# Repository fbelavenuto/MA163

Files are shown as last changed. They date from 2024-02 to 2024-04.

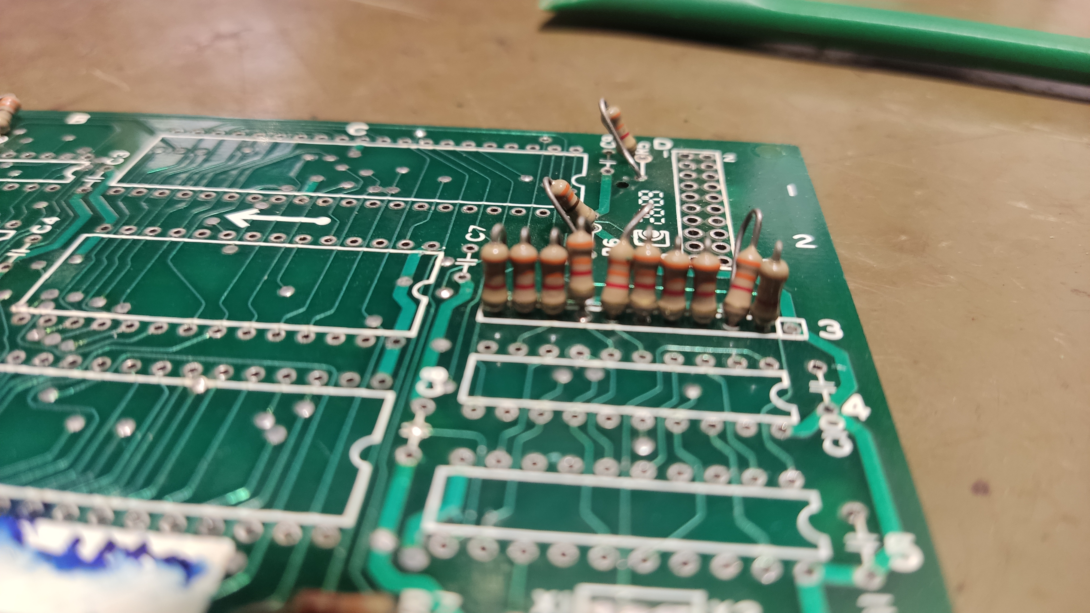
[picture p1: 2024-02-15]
Rev1/Docs/Foto02.jpg

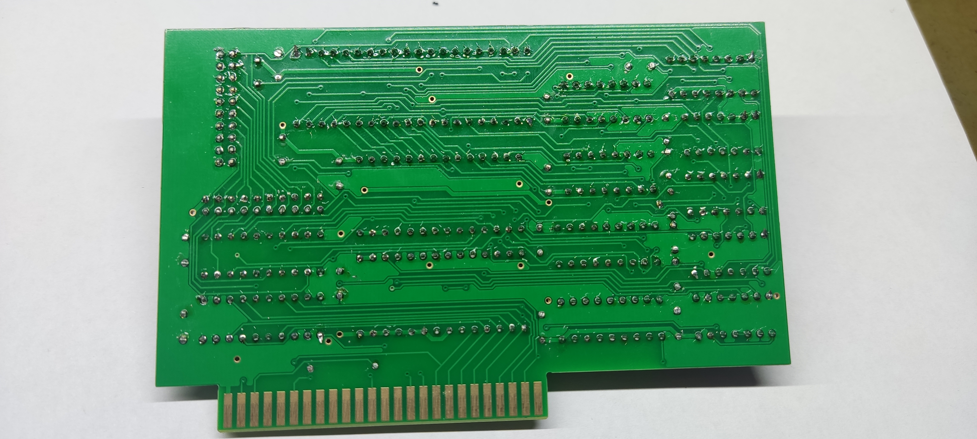
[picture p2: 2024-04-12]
Rev1/Docs/Montada-verso.jpg

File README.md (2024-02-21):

# MA163

Interface Paralela Microdigital para TK3000//e

Foi realizado uma engenharia reversa na interface paralela da Microdigital (MA163) para TK3000//e. O esquema da interface foi recriado junto com o roteamento da placa original, podendo assim ser produzido placas que funcionam como a original.

O manual original da interface digitalizado foi encontrado neste [link](http://www.apple-iigs.info/doc/fichiers/TK3000%20IIe%20Super%20parallel%20card.pdf), uma cópia do arquivo está neste repositório.

# Pastas

`Common` possui os binários das ROMs, seus *disassemblys* e uma cópia do manual original digitalizado.

Dentro da pasta [`Rev1`](Rev1) há três subpastas com os nomes `Docs`, `Eagle` e `Gerber`. O esquema elétrico em PDF, imagens, lista de materiais, etc, estão em `Docs`. Na subpasta *Eagle* há os arquivos originais para a versão 9 do software Autodesk Eagle. Para a confecção das placas há os arquivos em formato gerber na pasta `Gerber` que podem ser enviados para uma empresa de fabricação de PCBs.

# Montagem

A lista de material pode ser encontrada [aqui](Rev1/Docs/Lista%20material.md).

Para facilitar a montagem abra o arquivo [ibom.html](Rev1/Docs/ibom.html) localmente ou acesse [este link](https://fbelavenuto.github.io/pages/MA163-Rev1-ibom.html) para visualizar os componentes e seus lugares na placa. Criado com o projeto [InteractiveHtmlBom](https://github.com/openscopeproject/InteractiveHtmlBom), linha de comando: `generate_interactive_bom --highlight-pin1 all --blacklist-empty-val MA163.brd`

Soquetes para os CIs não estão na lista de material mas são altamente recomendados para facilitar futuras manutenções.

Há a opção de usar uma rede resistiva RN1 ou usar os resistores R8 a R17 no seu lugar.

A montagem das memórias dinâmicas são opcionais. Elas são utilizadas como buffer para liberar o micro antes de terminar a impressão. Sem as memórias o micro fica "travado" até terminar a impressão. Podem ser usadas memórias 4464 para ter um buffer maior de 64KB.

# Disassembly

Foi efetuado o disassembly nas duas ROMs da interface, uma ROM é para o Apple-2 e outra ROM é para o Z80. Por enquanto não foi entendido totalmente as funções mas a maioria das coisas principais foram entendidas e comentadas. Para estes trabalhos foi utilizado a versão 6.1 Pro do software IDA da Hex-Rays.

# Observações

É recomendado a fabricação com finalização ENIG ou ouro no conector Edge para mais durabilidade.

O jumper de solda da placa não precisa ser soldado, este jumper não tem utilidade pois se mudado desabilita a saída de dados para a impressora, tornando a interface inútil!

# Curiosidades

A ROM do Apple-2 não é linear! O pino A6 desta ROM é invertido e controlado pelo Z80 e /DEVSEL, sendo assim o código que aparece para o Apple-2 muda dinamicamente. O Z80 quando escreve no endereço $5000 define o sinal FLAG_FW em 1. Quando o firmware do Apple-2 escreve em $C0xx (ativando /DEVSEL) o sinal FLAG_FW vai para 0.

O sinal FLAG_FW se em 1 faz A6 ficar invertido quando o Apple-2 acessa de $Cx00 a $Cx7F e ao acessar $Cx80 a $CxFF o sinal A6 é mantido sempre em 1. Se FLAG_FW for 0 o sinal A6 fica invertido sempre.

No TK3000//e o status da tecla MODE aparece no pino `INTIN` do slot 1. Se MODE estiver desabilitado o pino `INTIN` fica em 1.

Para a leitura de flags o Z80 utiliza o opcode `IN A,(0)`, porém a operação de I/O não é decodificada! O truque é que os sinais são forçados no barramento de dados com resistores, assim ao executar o `IN` o Z80 deixa o barramento livre e os resistores forçam o sinal que é lido corretamente. O status da tecla MODE vai no pino D5, o sinal BUSY vai no pino D6 via resistor R2 e o sinal !FLAG_FW vai no pino D7 via resistor R4.

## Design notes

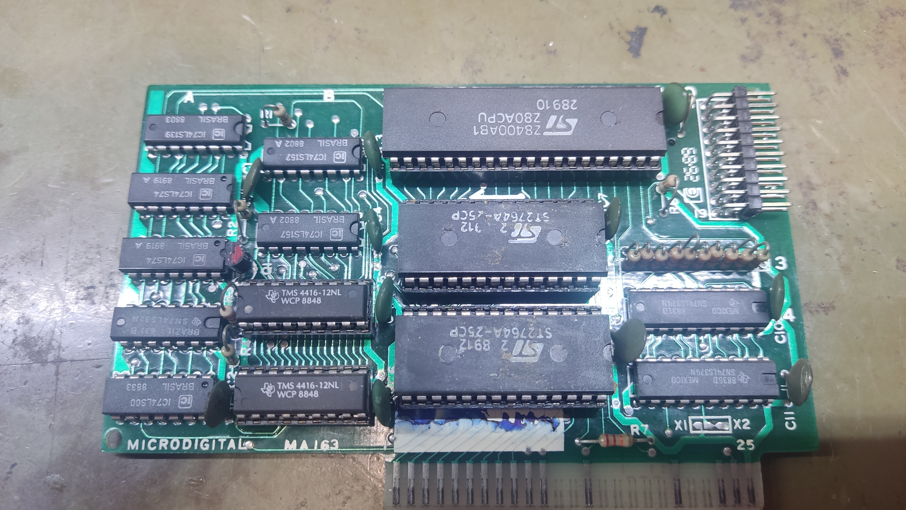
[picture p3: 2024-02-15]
Rev1/Docs/Foto01.jpg

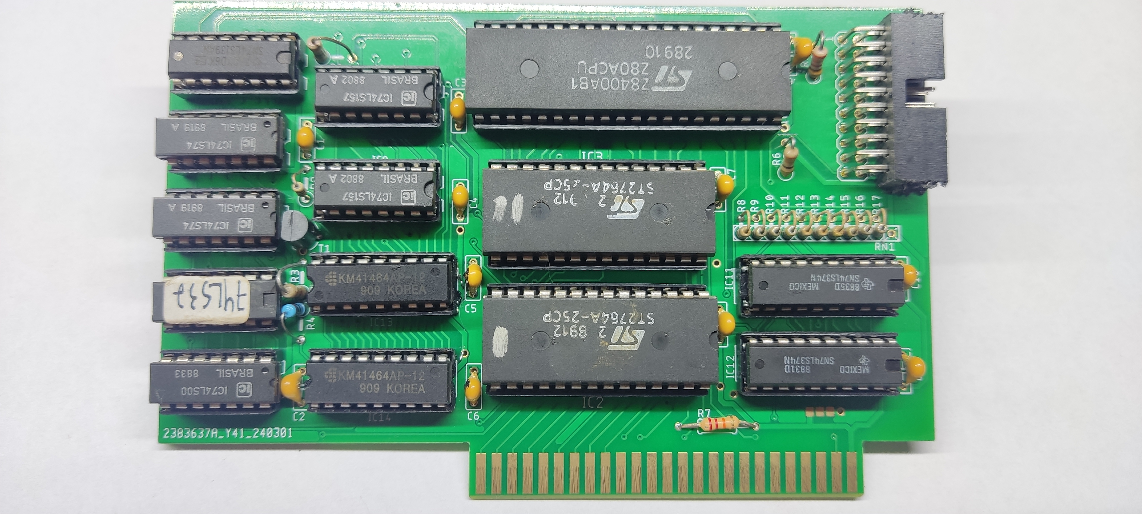
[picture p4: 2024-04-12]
Rev1/Docs/Montada-frente.jpg

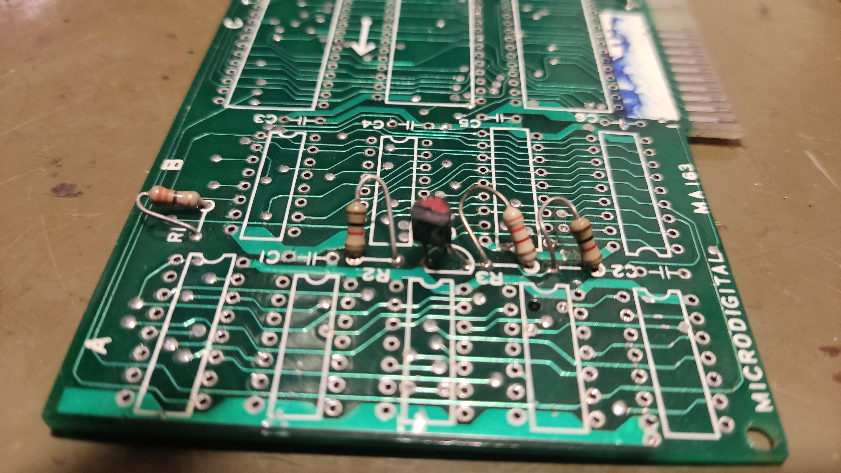
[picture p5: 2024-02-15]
Rev1/Docs/Foto04.jpg

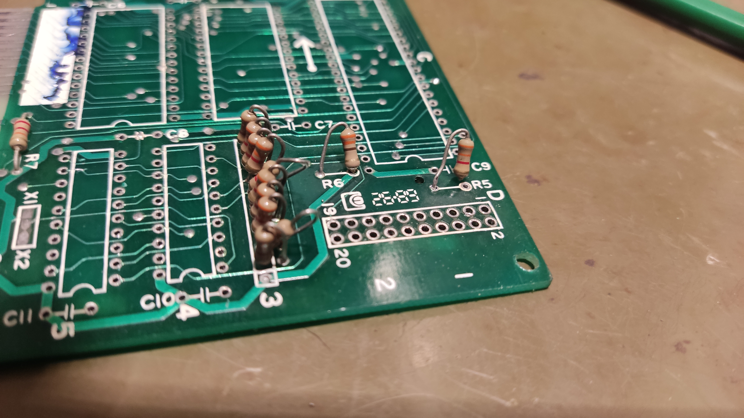
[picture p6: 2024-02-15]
Rev1/Docs/Foto03.jpg

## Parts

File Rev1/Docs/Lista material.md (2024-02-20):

# Lista de material

## Resistores

Todos são resistores de 1/4W

| Qtde | Valor | Obs |
|:----:|---|-----|
| 2 | 330Ω  | |
| 2 | 1K | |
| 1 | 22K | |
| 2 | 3K3 | |
| 10 | 3K3 | Se não for usar RN1 |
| 1 | 10x3K3 | Opção para usar no lugar dos resistores R8 à R17 |

## Capacitores

| Qtde | Valor | Tipo |
|:----:|---|---|
|  11  | 100n  | Cerâmico ou Poliester |

## Transistores

| Qtde | Valor |
|:----:|---|
| 1 | BC548 |

## Circuitos Integrados

2   74LS374N      74LS374N        DIL20        IC11, IC12                                     Octal D type transparent LATCH, edge triggered

| Qtde | Valor | Obs |
|:----:|---|-----|
| 1 | Z80 | CPU 4MHz |
| 2 | 27C64 | Gravar conteúdo dos arquivos [ROMs](../../Common) |
| 2 | TMS4416 ou TMS4464 | Opcional |
| 1 | 74LS00 | DIL |
| 1 | 74LS32 | DIL |
| 2 | 74LS74 | DIL |
| 1 | 74LS139 | DIL |
| 1 | 74LS157 | DIL |
| 2 | 74LS374 | DIL |

## Soquetes (opcional)

| Qtde | Tipo |
|:----:|---|
| 1 | 40 pinos |
| 2 | 28 pinos (largo) |
| 2 | 20 pinos |
| 2 | 18 pinos |
| 3 | 16 pinos |
| 4 | 14 pinos |

## Diversos

| Qtde | Valor | Modelo |
|:----:|---|---|
| 1 | Pinheader 2x10 pinos 90º | 2,54mm |

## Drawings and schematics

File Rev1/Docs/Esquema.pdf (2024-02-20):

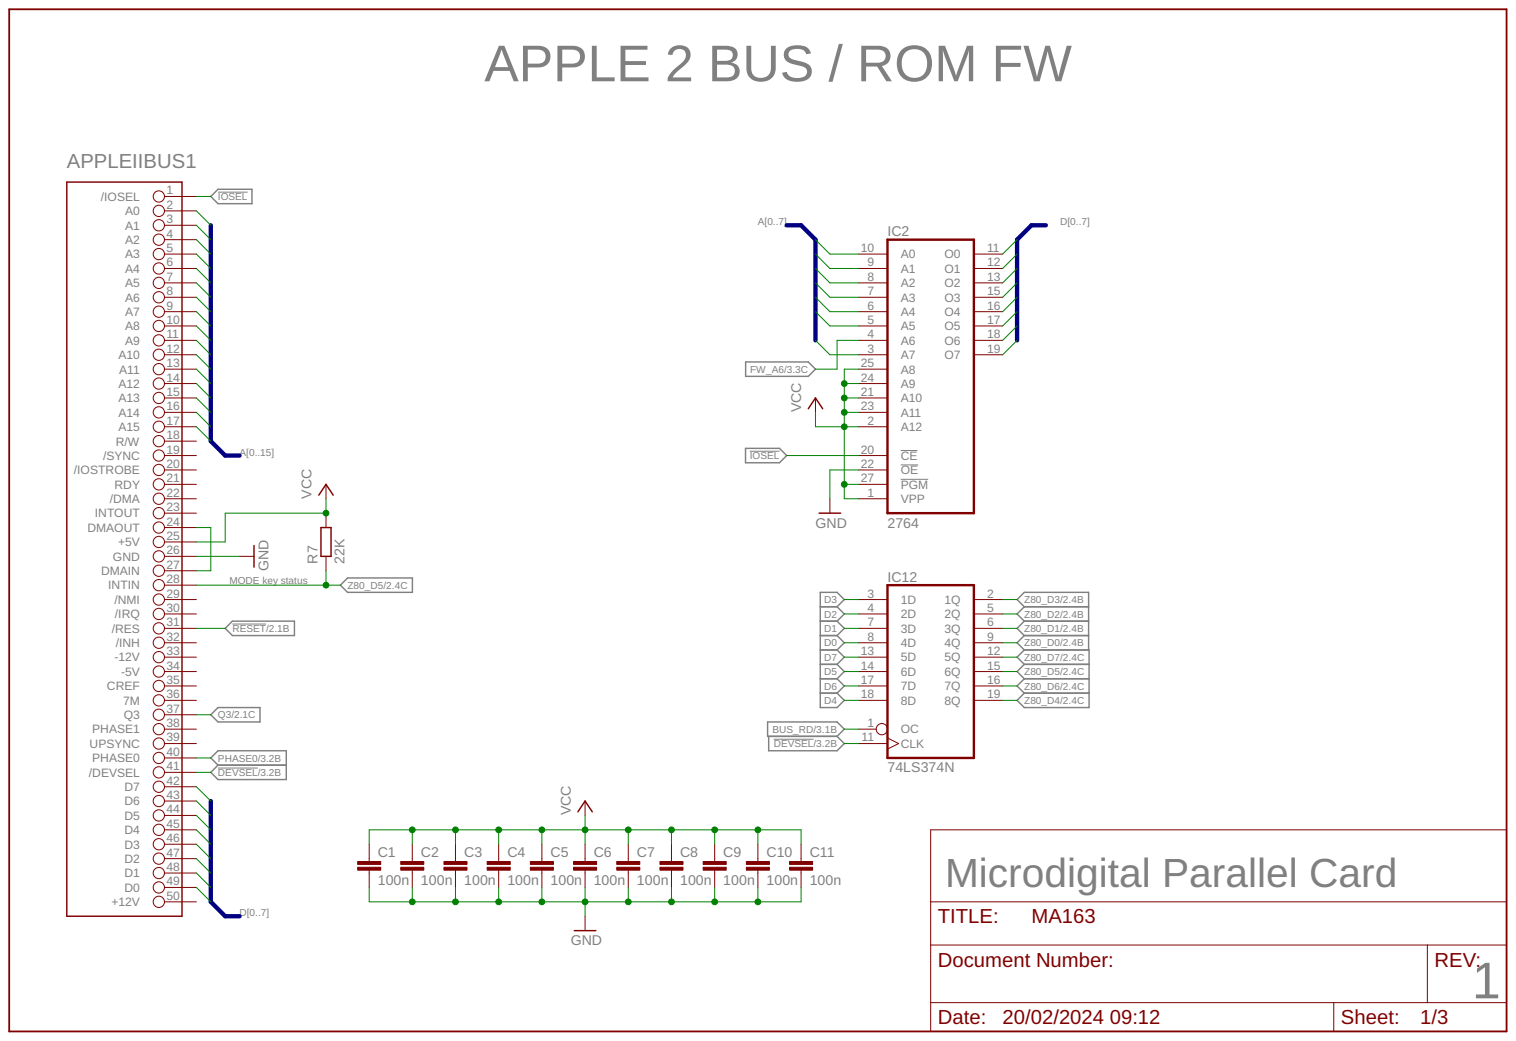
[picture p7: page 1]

APPLE 2 BUS / ROM FW

MODE key status GND

Document Number: | REV: 1

Date: 20/02/2024 09:12 | Sheet: 1/3

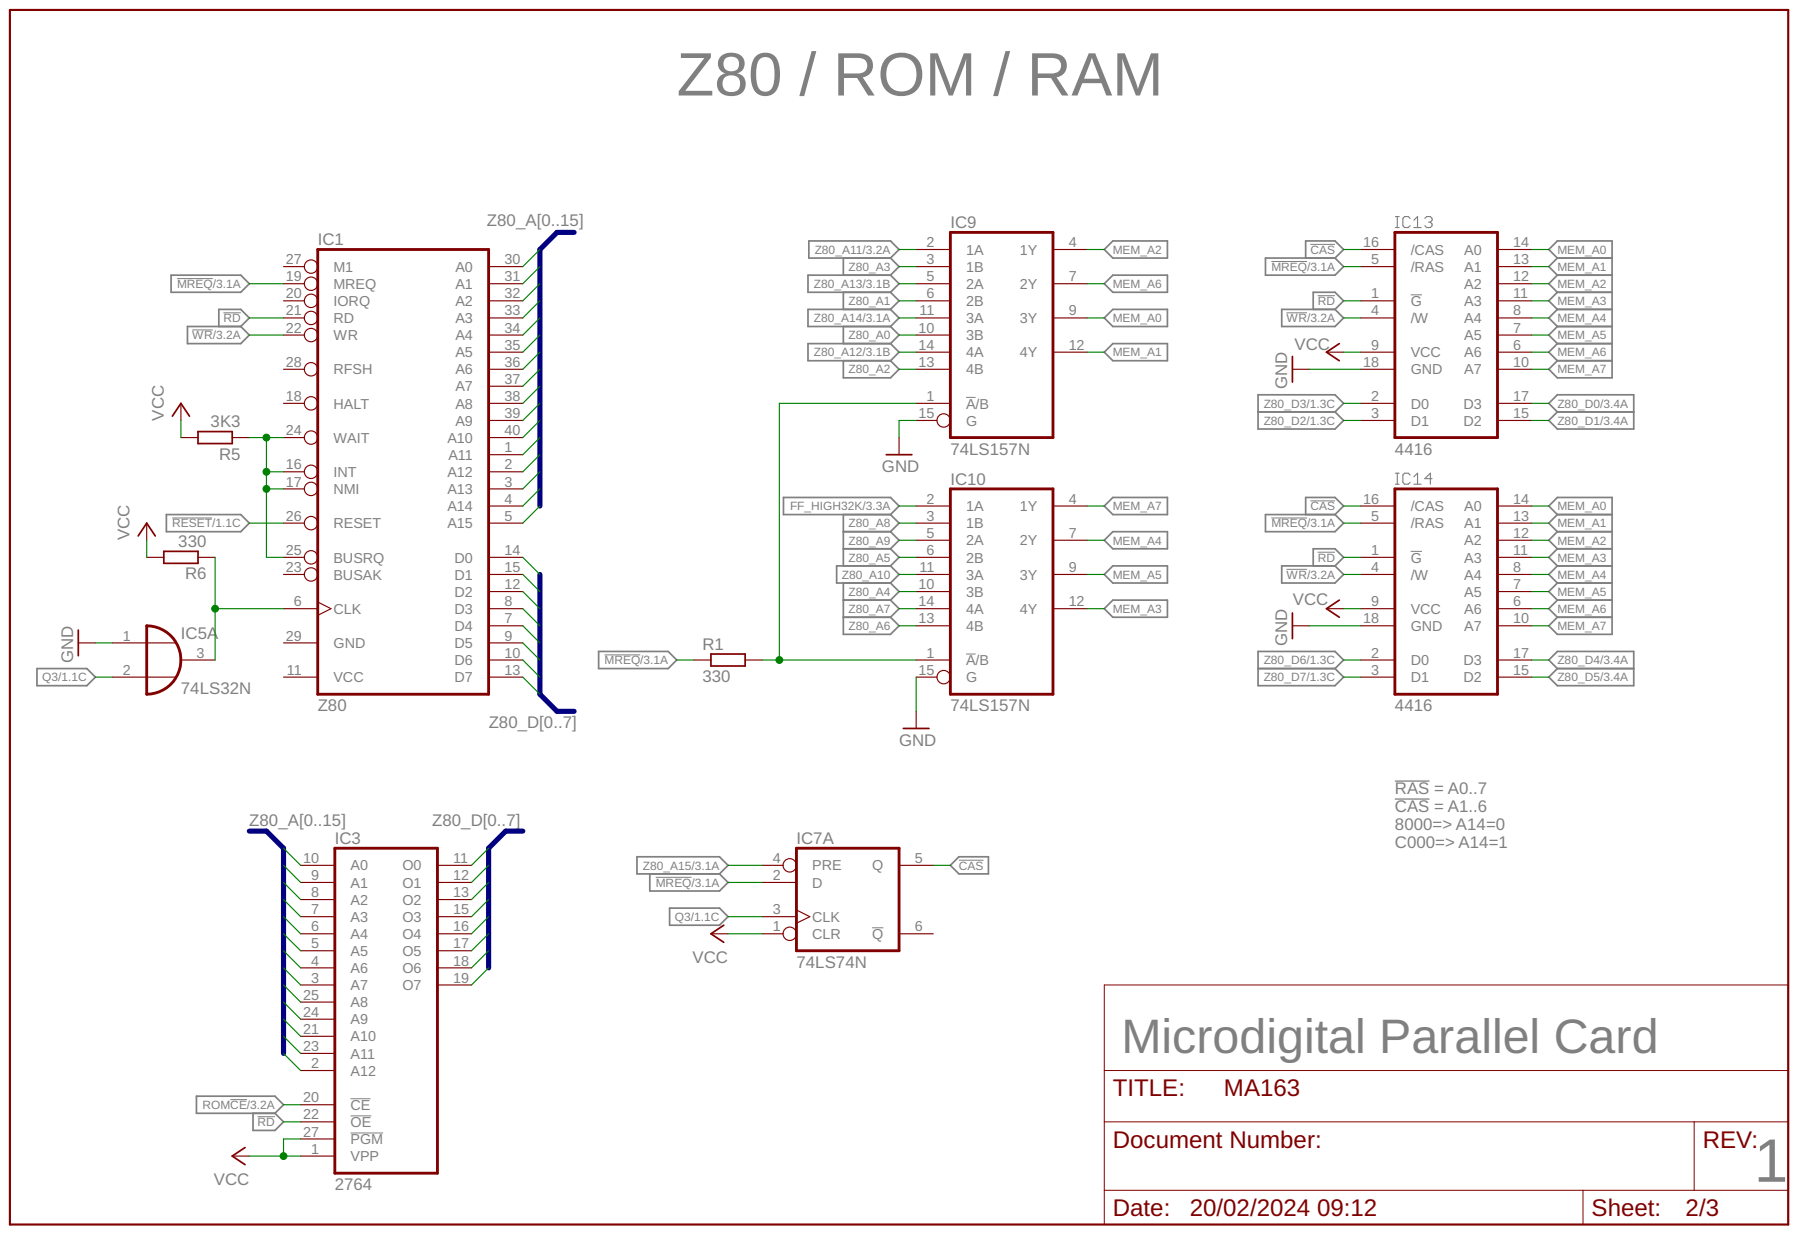
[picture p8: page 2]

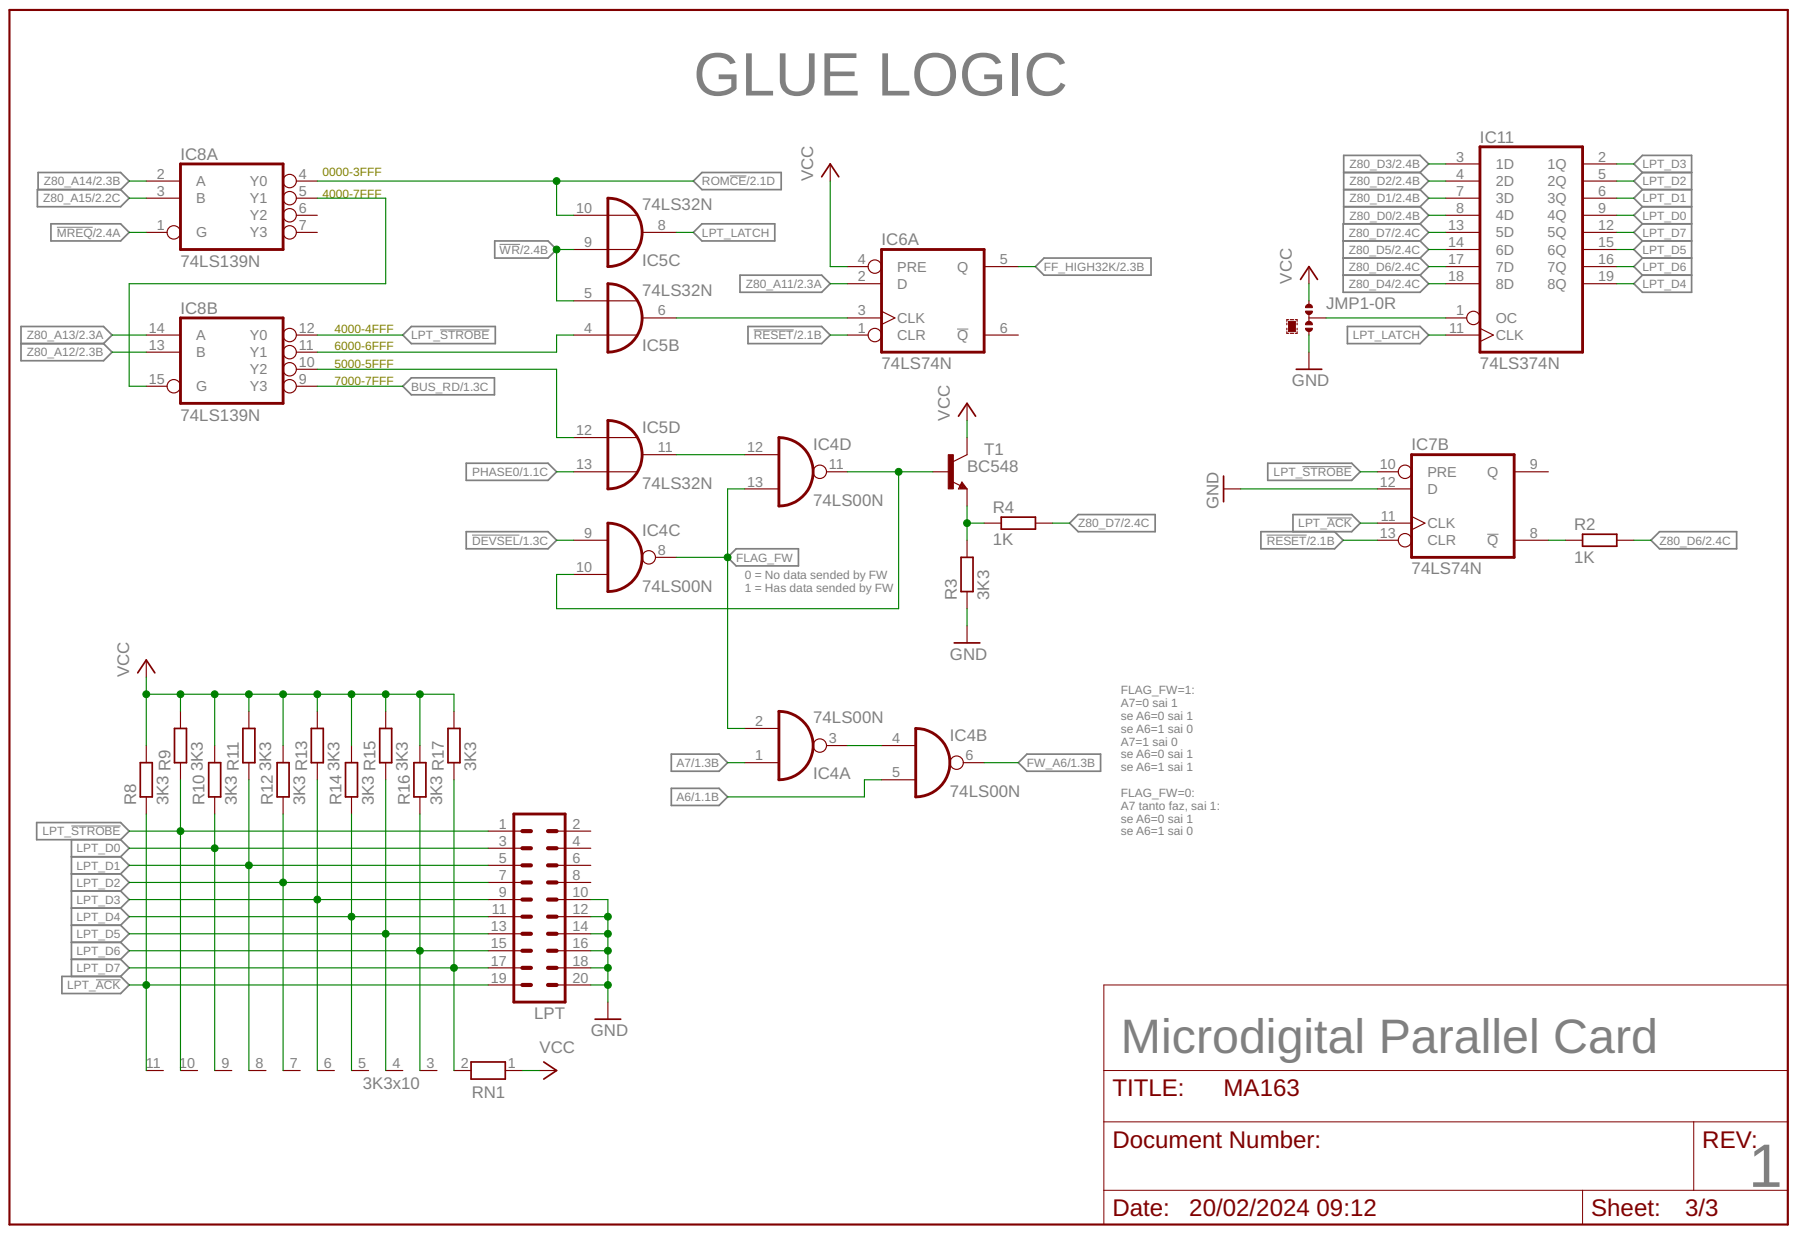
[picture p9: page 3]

FLAG_FW
0 = No data sended by FW

se A6=0 sai 1
se A6=1 sai 1 FLAG_FW=0: A7 tanto faz, sai 1: se A6=0 sai 1

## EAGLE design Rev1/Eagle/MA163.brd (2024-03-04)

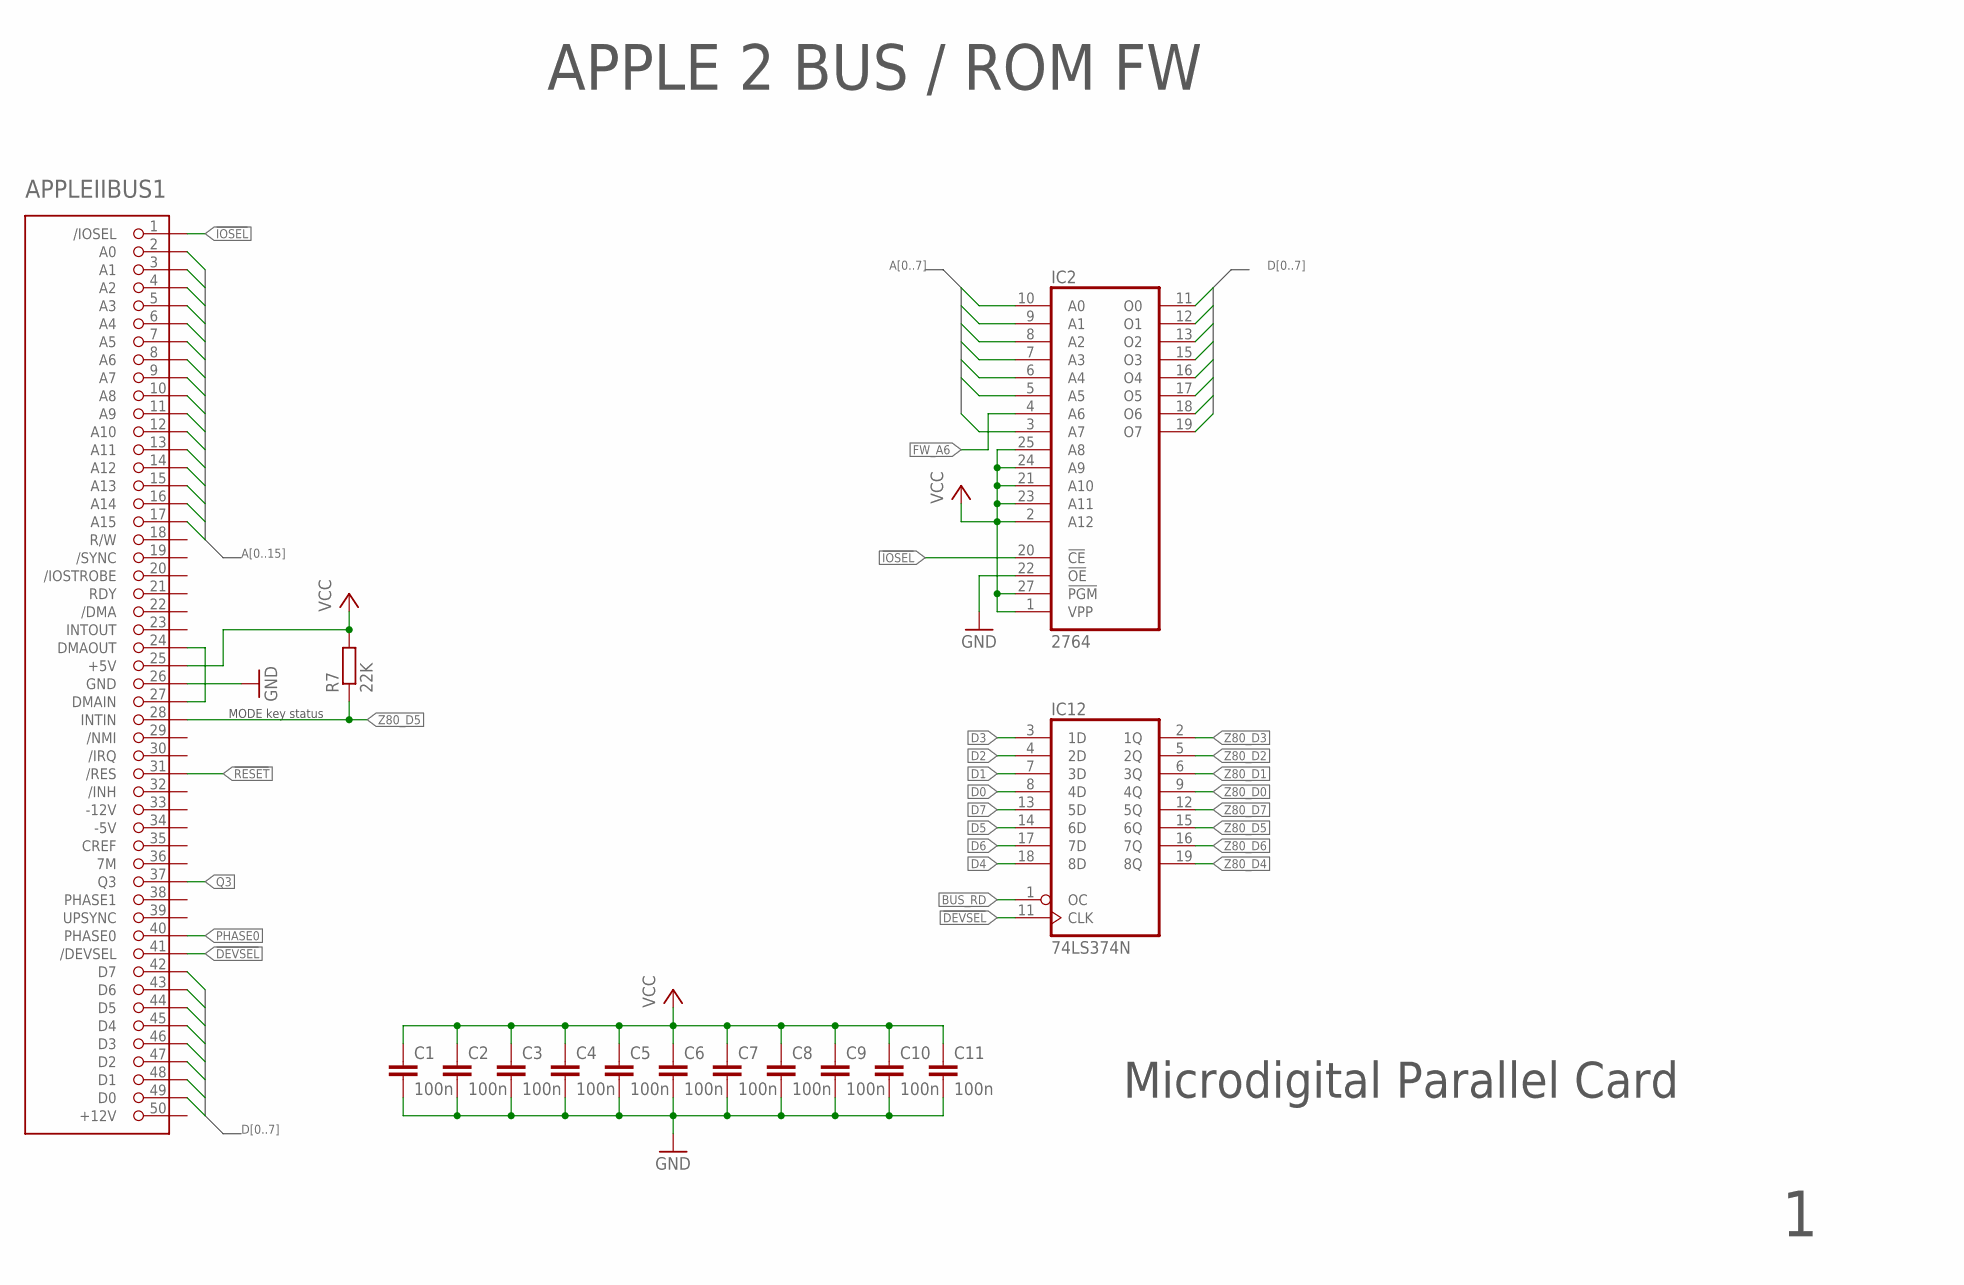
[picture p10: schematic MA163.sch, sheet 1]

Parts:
APPLEIIBUS1: APPLEIIBUS2X4; SLOT
C1, C2, C3, C4, C5, C6, C7, C8, C9, C10, C11: 100n; C050-025X075
IC2: 2764; DIL28
IC12: 74LS374N; DIL20
R7: 22K; 0207/12

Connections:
!DEVSEL: APPLEIIBUS1.41 (/DEVSEL), IC12.11 (CLK); also elsewhere on the board
!IOSEL: APPLEIIBUS1.1 (/IOSEL), IC2.20 (!CE)
!RESET: APPLEIIBUS1.31 (/RES); also elsewhere on the board
A0: APPLEIIBUS1.2 (A0), IC2.10 (A0)
A1: APPLEIIBUS1.3 (A1), IC2.9 (A1)
A2: APPLEIIBUS1.4 (A2), IC2.8 (A2)
A3: APPLEIIBUS1.5 (A3), IC2.7 (A3)
A4: APPLEIIBUS1.6 (A4), IC2.6 (A4)
A5: APPLEIIBUS1.7 (A5), IC2.5 (A5)
A6: APPLEIIBUS1.8 (A6); also elsewhere on the board
A7: APPLEIIBUS1.9 (A7), IC2.3 (A7); also elsewhere on the board
A8: APPLEIIBUS1.10 (A8)
A9: APPLEIIBUS1.11 (A9)
A10: APPLEIIBUS1.12 (A10)
A11: APPLEIIBUS1.13 (A11)
A12: APPLEIIBUS1.14 (A12)
A13: APPLEIIBUS1.15 (A13)
A14: APPLEIIBUS1.16 (A14)
A15: APPLEIIBUS1.17 (A15)
BUS_RD: IC12.1 (OC); also elsewhere on the board
D0: APPLEIIBUS1.49 (D0), IC2.11 (O0), IC12.8 (4D)
D1: APPLEIIBUS1.48 (D1), IC2.12 (O1), IC12.7 (3D)
D2: APPLEIIBUS1.47 (D2), IC2.13 (O2), IC12.4 (2D)
D3: APPLEIIBUS1.46 (D3), IC2.15 (O3), IC12.3 (1D)
D4: APPLEIIBUS1.45 (D4), IC2.16 (O4), IC12.18 (8D)
D5: APPLEIIBUS1.44 (D5), IC2.17 (O5), IC12.14 (6D)
D6: APPLEIIBUS1.43 (D6), IC2.18 (O6), IC12.17 (7D)
D7: APPLEIIBUS1.42 (D7), IC2.19 (O7), IC12.13 (5D)
FW_A6: IC2.4 (A6); also elsewhere on the board
GND: APPLEIIBUS1.26 (GND), C1.2, C2.2, C3.2, C4.2, C5.2, C6.2, C7.2, C8.2, C9.2, C10.2, C11.2, IC2.14 (GND), IC2.22 (!OE), IC12.10 (GND); also elsewhere on the board
unnamed: APPLEIIBUS1.24 (DMAOUT), APPLEIIBUS1.27 (DMAIN)
PHASE0: APPLEIIBUS1.40 (PHASE0); also elsewhere on the board
Q3: APPLEIIBUS1.37 (Q3); also elsewhere on the board
VCC: APPLEIIBUS1.25 (+5V), C1.1, C2.1, C3.1, C4.1, C5.1, C6.1, C7.1, C8.1, C9.1, C10.1, C11.1, IC2.1 (VPP), IC2.2 (A12), IC2.21 (A10), IC2.23 (A11), IC2.24 (A9), IC2.25 (A8), IC2.27 (!PGM), IC2.28 (VCC), IC12.20 (VCC), R7.2; also elsewhere on the board
Z80_D0: IC12.9 (4Q); also elsewhere on the board
Z80_D1: IC12.6 (3Q); also elsewhere on the board
Z80_D2: IC12.5 (2Q); also elsewhere on the board
Z80_D3: IC12.2 (1Q); also elsewhere on the board
Z80_D4: IC12.19 (8Q); also elsewhere on the board
Z80_D5: APPLEIIBUS1.28 (INTIN), IC12.15 (6Q), R7.1; also elsewhere on the board
Z80_D6: IC12.16 (7Q); also elsewhere on the board
Z80_D7: IC12.12 (5Q); also elsewhere on the board

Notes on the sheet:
Microdigital Parallel Card
APPLE 2 BUS / ROM FW
MODE key status

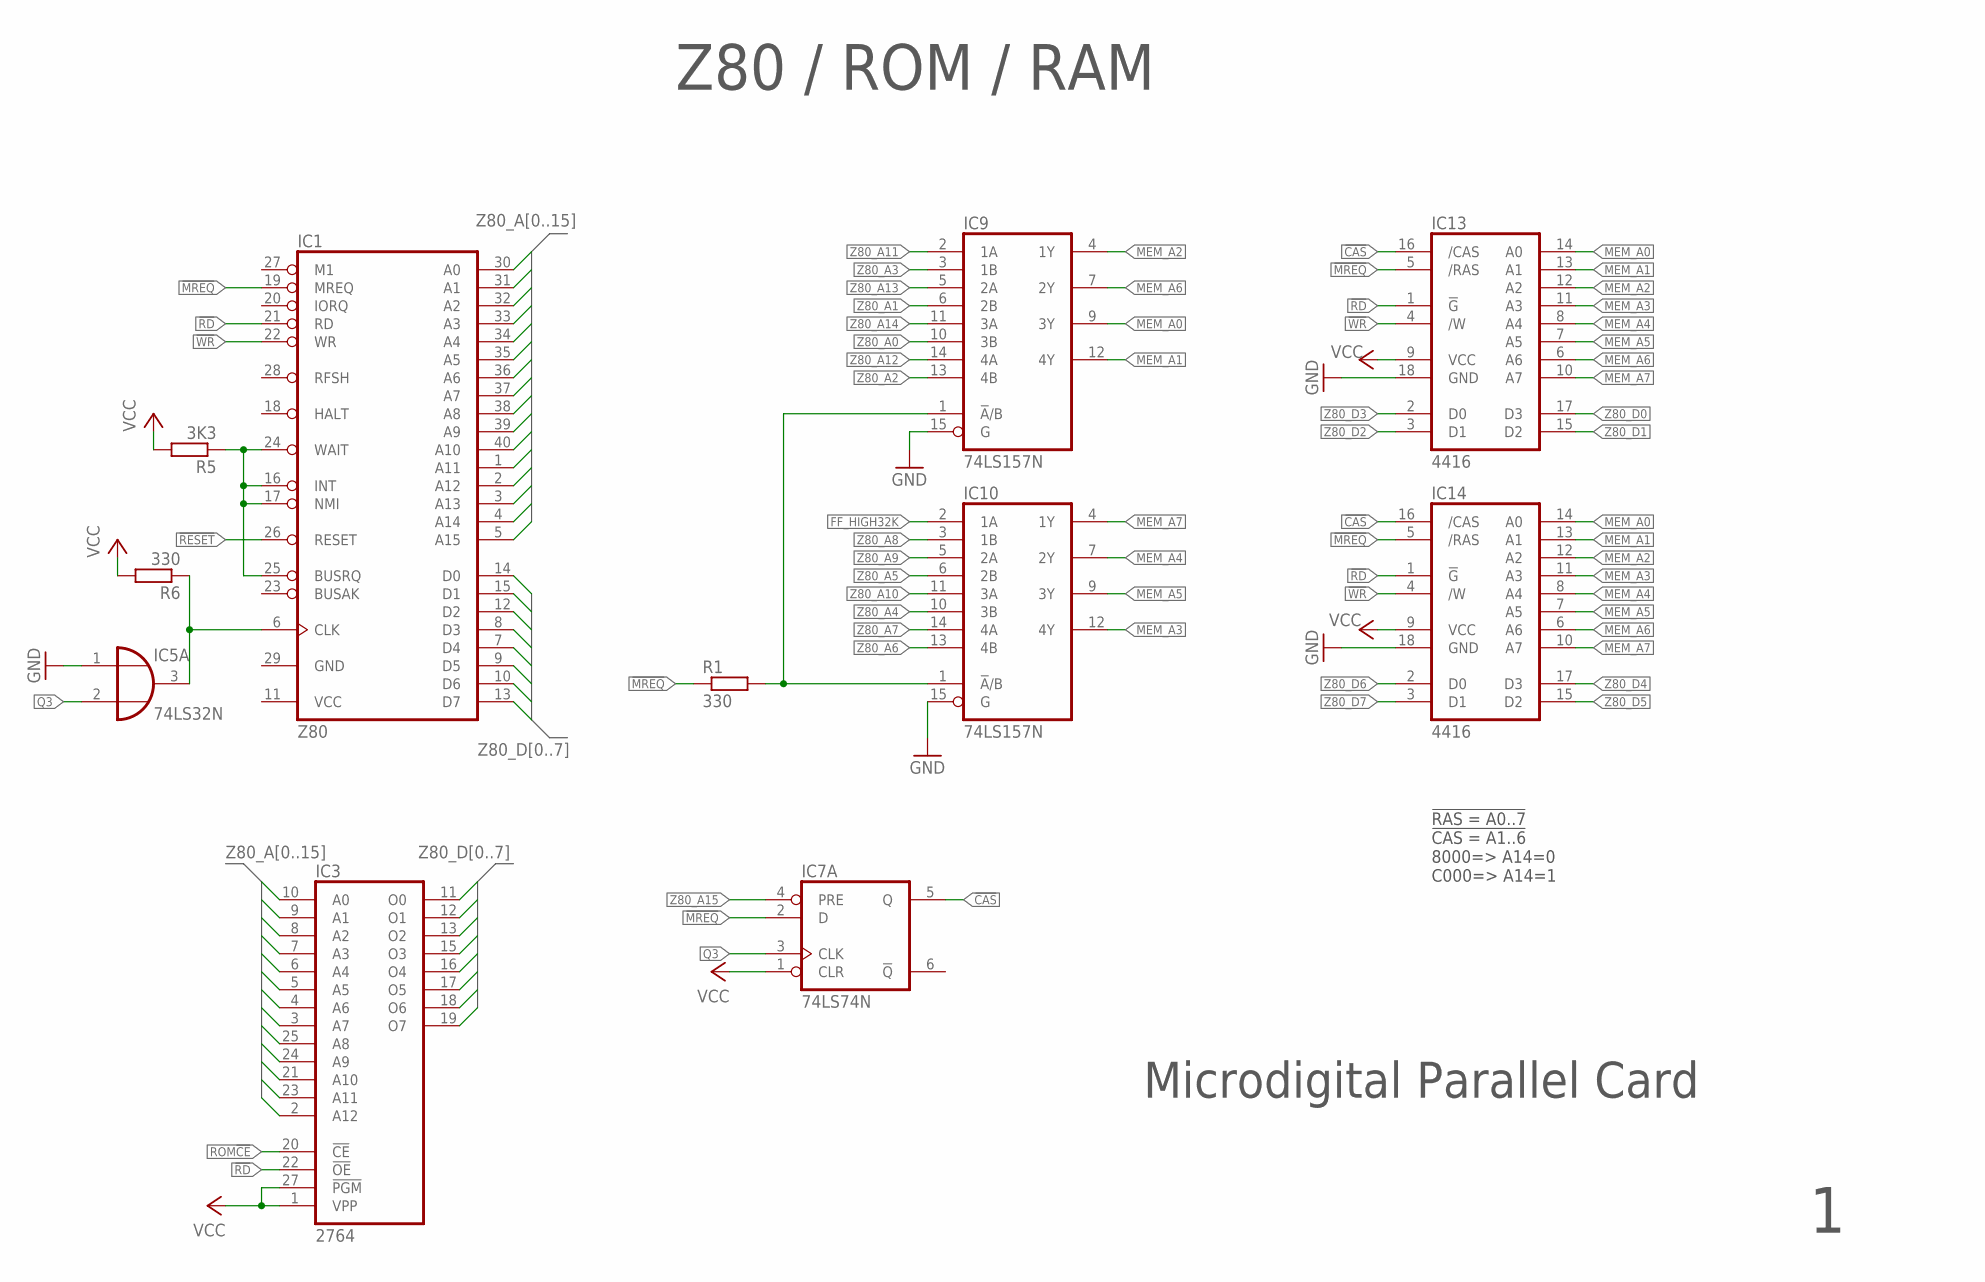
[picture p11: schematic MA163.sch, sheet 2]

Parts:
IC1: Z80; DIL40
IC3: 2764; DIL28
IC5: 74LS32N; DIL14
IC7: 74LS74N; DIL14
IC9, IC10: 74LS157N; DIL16
IC13, IC14: 4416; DIL18
R1, R6: 330; 0207/5V
R5: 3K3; 0207/5V

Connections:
!CAS: IC7.5 (Q), IC13.16 (/CAS), IC14.16 (/CAS)
!MREQ: IC1.19 (MREQ), IC7.2 (D), IC13.5 (/RAS), IC14.5 (/RAS), R1.1; also elsewhere on the board
!RD: IC1.21 (RD), IC3.22 (!OE), IC13.1 (!G), IC14.1 (!G)
!RESET: IC1.26 (RESET); also elsewhere on the board
!WR: IC1.22 (WR), IC13.4 (/W), IC14.4 (/W); also elsewhere on the board
!Z80_CLK: IC1.6 (CLK), IC5.3 (O), R6.1
FF_HIGH32K: IC10.2 (1A); also elsewhere on the board
GND: IC1.29 (GND), IC3.14 (GND), IC5.1 (I0), IC5.7 (GND), IC7.7 (GND), IC9.8 (GND), IC9.15 (G), IC10.8 (GND), IC10.15 (G), IC13.18 (GND), IC14.18 (GND); also elsewhere on the board
MEM_A0: IC9.9 (3Y), IC13.14 (A0), IC14.14 (A0)
MEM_A1: IC9.12 (4Y), IC13.13 (A1), IC14.13 (A1)
MEM_A2: IC9.4 (1Y), IC13.12 (A2), IC14.12 (A2)
MEM_A3: IC10.12 (4Y), IC13.11 (A3), IC14.11 (A3)
MEM_A4: IC10.7 (2Y), IC13.8 (A4), IC14.8 (A4)
MEM_A5: IC10.9 (3Y), IC13.7 (A5), IC14.7 (A5)
MEM_A6: IC9.7 (2Y), IC13.6 (A6), IC14.6 (A6)
MEM_A7: IC10.4 (1Y), IC13.10 (A7), IC14.10 (A7)
unnamed: IC1.16 (INT), IC1.17 (NMI), IC1.24 (WAIT), IC1.25 (BUSRQ), R5.1
unnamed: IC9.1 (!A!/B), IC10.1 (!A!/B), R1.2
Q3: IC5.2 (I1), IC7.3 (CLK); also elsewhere on the board
ROM!CE: IC3.20 (!CE); also elsewhere on the board
VCC: IC1.11 (VCC), IC3.1 (VPP), IC3.27 (!PGM), IC3.28 (VCC), IC5.14 (VCC), IC7.1 (CLR), IC7.14 (VCC), IC9.16 (VCC), IC10.16 (VCC), IC13.9 (VCC), IC14.9 (VCC), R5.2, R6.2; also elsewhere on the board
Z80_A0: IC1.30 (A0), IC3.10 (A0), IC9.10 (3B)
Z80_A1: IC1.31 (A1), IC3.9 (A1), IC9.6 (2B)
Z80_A2: IC1.32 (A2), IC3.8 (A2), IC9.13 (4B)
Z80_A3: IC1.33 (A3), IC3.7 (A3), IC9.3 (1B)
Z80_A4: IC1.34 (A4), IC3.6 (A4), IC10.10 (3B)
Z80_A5: IC1.35 (A5), IC3.5 (A5), IC10.6 (2B)
Z80_A6: IC1.36 (A6), IC3.4 (A6), IC10.13 (4B)
Z80_A7: IC1.37 (A7), IC3.3 (A7), IC10.14 (4A)
Z80_A8: IC1.38 (A8), IC3.25 (A8), IC10.3 (1B)
Z80_A9: IC1.39 (A9), IC3.24 (A9), IC10.5 (2A)
Z80_A10: IC1.40 (A10), IC3.21 (A10), IC10.11 (3A)
Z80_A11: IC1.1 (A11), IC3.23 (A11), IC9.2 (1A); also elsewhere on the board
Z80_A12: IC1.2 (A12), IC3.2 (A12), IC9.14 (4A); also elsewhere on the board
Z80_A13: IC1.3 (A13), IC9.5 (2A); also elsewhere on the board
Z80_A14: IC1.4 (A14), IC9.11 (3A); also elsewhere on the board
Z80_A15: IC1.5 (A15), IC7.4 (PRE); also elsewhere on the board
Z80_D0: IC1.14 (D0), IC3.11 (O0), IC13.17 (D3); also elsewhere on the board
Z80_D1: IC1.15 (D1), IC3.12 (O1), IC13.15 (D2); also elsewhere on the board
Z80_D2: IC1.12 (D2), IC3.13 (O2), IC13.3 (D1); also elsewhere on the board
Z80_D3: IC1.8 (D3), IC3.15 (O3), IC13.2 (D0); also elsewhere on the board
Z80_D4: IC1.7 (D4), IC3.16 (O4), IC14.17 (D3); also elsewhere on the board
Z80_D5: IC1.9 (D5), IC3.17 (O5), IC14.15 (D2); also elsewhere on the board
Z80_D6: IC1.10 (D6), IC3.18 (O6), IC14.2 (D0); also elsewhere on the board
Z80_D7: IC1.13 (D7), IC3.19 (O7), IC14.3 (D1); also elsewhere on the board

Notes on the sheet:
Microdigital Parallel Card
Z80 / ROM / RAM
!RAS = A0..7 !CAS = A1..6 8000=> A14=0 C000=> A14=1

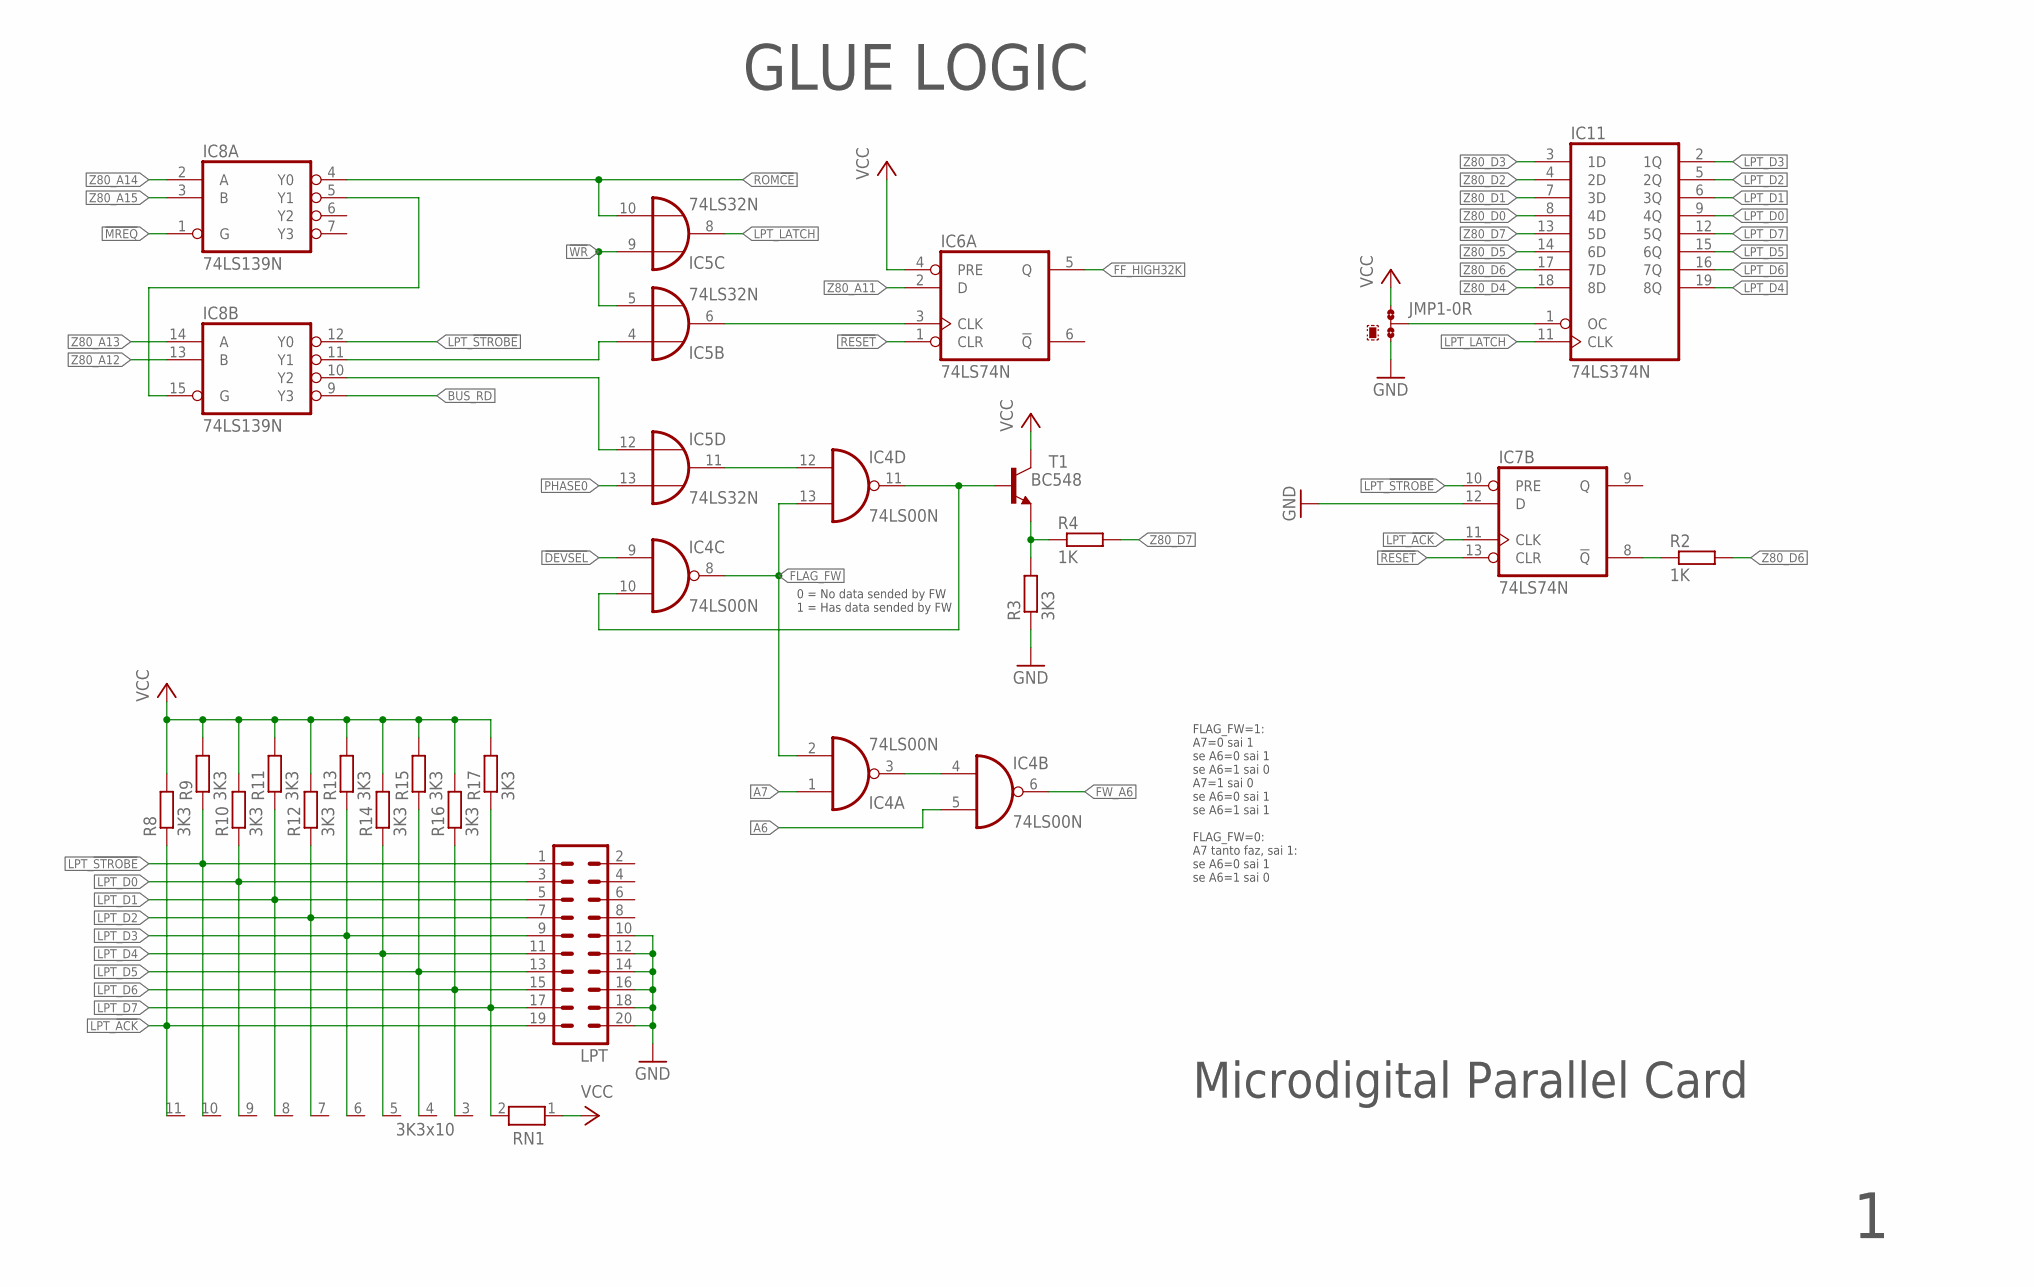
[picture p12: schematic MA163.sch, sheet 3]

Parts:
IC4: 74LS00N; DIL14
IC5: 74LS32N; DIL14
IC6, IC7: 74LS74N; DIL14
IC8: 74LS139N; DIL16
IC11: 74LS374N; DIL20
JMP1: 0R-JUMPB; B0R-JMP
LPT: MA10-2
R2, R4: 1K; 0207/5V
R3: 3K3; 0207/5V
R8, R9, R10, R11, R12, R13, R14, R15, R16, R17: 3K3; 0207/2V
RN1: 3K3x10; RN-11
T1: BC548; TO92L

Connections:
!DEVSEL: IC4.9 (I0); also elsewhere on the board
!MREQ: IC8.1 (G); also elsewhere on the board
!RESET: IC6.1 (CLR), IC7.13 (CLR); also elsewhere on the board
!WR: IC5.5 (I1), IC5.9 (I0); also elsewhere on the board
A6: IC4.5 (I1); also elsewhere on the board
A7: IC4.1 (I0); also elsewhere on the board
BUS_RD: IC8.9 (Y3); also elsewhere on the board
FF_HIGH32K: IC6.5 (Q); also elsewhere on the board
FLAG_FW: IC4.2 (I1), IC4.8 (O), IC4.13 (I1)
FW_A6: IC4.6 (O); also elsewhere on the board
GND: IC4.7 (GND), IC5.7 (GND), IC6.7 (GND), IC7.7 (GND), IC7.12 (D), IC8.8 (GND), IC11.10 (GND), JMP1.3, LPT.10, LPT.12, LPT.14, LPT.16, LPT.18, LPT.20, R3.1; also elsewhere on the board
LPT_!ACK: IC7.11 (CLK), LPT.19, R8.1, RN1.11
LPT_!STROBE: IC7.10 (PRE), IC8.12 (Y0), LPT.1, R9.1, RN1.10
LPT_D0: IC11.9 (4Q), LPT.3, R10.1, RN1.9
LPT_D1: IC11.6 (3Q), LPT.5, R11.1, RN1.8
LPT_D2: IC11.5 (2Q), LPT.7, R12.1, RN1.7
LPT_D3: IC11.2 (1Q), LPT.9, R13.1, RN1.6
LPT_D4: IC11.19 (8Q), LPT.11, R14.1, RN1.5
LPT_D5: IC11.15 (6Q), LPT.13, R15.1, RN1.4
LPT_D6: IC11.16 (7Q), LPT.15, R16.1, RN1.3
LPT_D7: IC11.12 (5Q), LPT.17, R17.1, RN1.2
LPT_LATCH: IC5.8 (O), IC11.11 (CLK)
unnamed: IC7.8 (!Q), R2.1
unnamed: R3.2, R4.1, T1.1 (E)
unnamed: IC5.4 (I0), IC8.11 (Y1)
unnamed: IC4.3 (O), IC4.4 (I0)
unnamed: IC8.5 (Y1), IC8.15 (G)
unnamed: IC11.1 (OC), JMP1.2
unnamed: IC4.10 (I1), IC4.11 (O), T1.2 (B)
unnamed: IC4.12 (I0), IC5.11 (O)
unnamed: IC5.6 (O), IC6.3 (CLK)
unnamed: IC5.12 (I0), IC8.10 (Y2)
PHASE0: IC5.13 (I1); also elsewhere on the board
ROM!CE: IC5.10 (I1), IC8.4 (Y0); also elsewhere on the board
VCC: IC4.14 (VCC), IC5.14 (VCC), IC6.4 (PRE), IC6.14 (VCC), IC7.14 (VCC), IC8.16 (VCC), IC11.20 (VCC), JMP1.1, R8.2, R9.2, R10.2, R11.2, R12.2, R13.2, R14.2, R15.2, R16.2, R17.2, RN1.1, T1.3 (C); also elsewhere on the board
Z80_A11: IC6.2 (D); also elsewhere on the board
Z80_A12: IC8.13 (B); also elsewhere on the board
Z80_A13: IC8.14 (A); also elsewhere on the board
Z80_A14: IC8.2 (A); also elsewhere on the board
Z80_A15: IC8.3 (B); also elsewhere on the board
Z80_D0: IC11.8 (4D); also elsewhere on the board
Z80_D1: IC11.7 (3D); also elsewhere on the board
Z80_D2: IC11.4 (2D); also elsewhere on the board
Z80_D3: IC11.3 (1D); also elsewhere on the board
Z80_D4: IC11.18 (8D); also elsewhere on the board
Z80_D5: IC11.14 (6D); also elsewhere on the board
Z80_D6: IC11.17 (7D), R2.2; also elsewhere on the board
Z80_D7: IC11.13 (5D), R4.2; also elsewhere on the board

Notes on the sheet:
GLUE LOGIC
FLAG_FW=1: A7=0 sai 1 se A6=0 sai 1 se A6=1 sai 0 A7=1 sai 0 se A6=0 sai 1 se A6=1 sai 1 FLAG_FW=0: A7 tanto faz, sai 1: se A6=0 sai 1 se A6=1 sai 0
0 = No data sended by FW 1 = Has data sended by FW
Microdigital Parallel Card

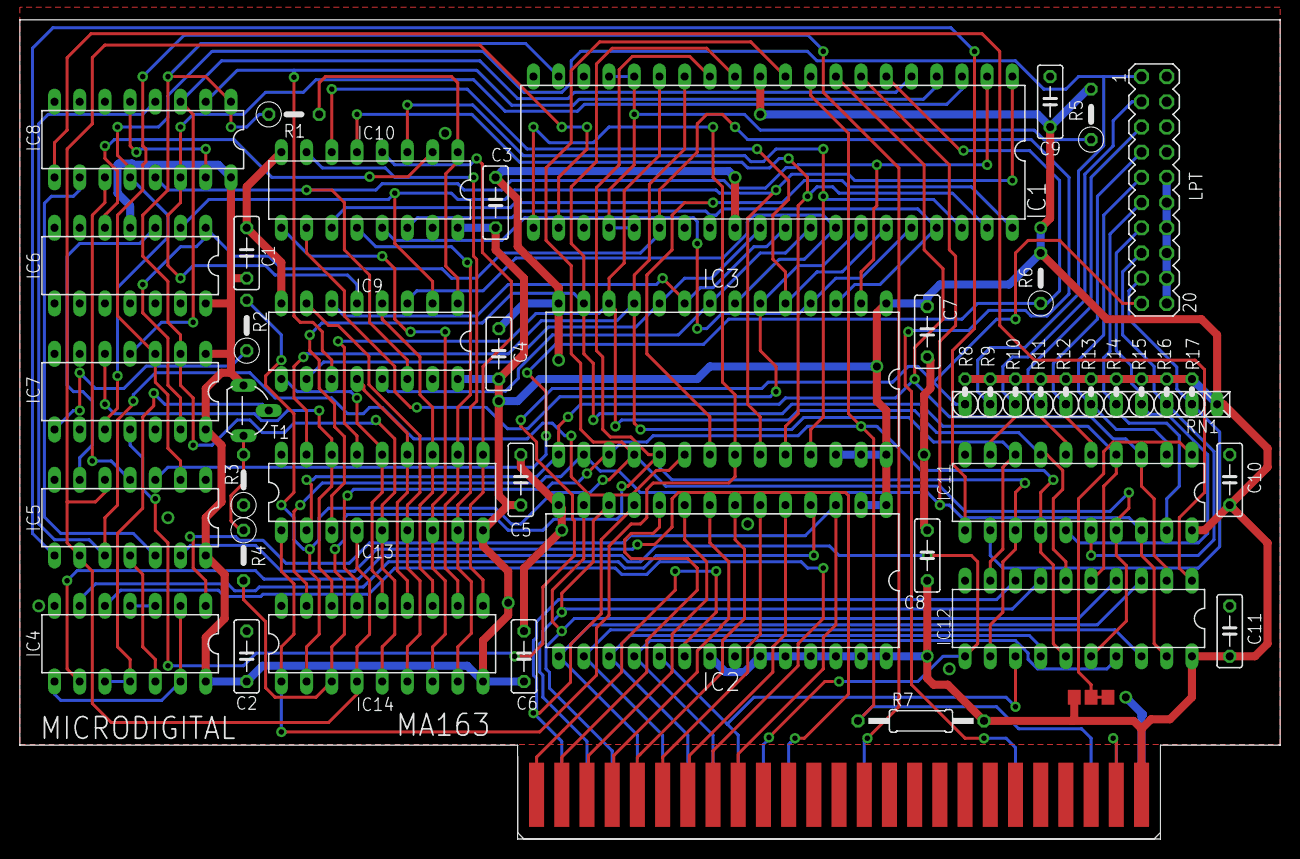
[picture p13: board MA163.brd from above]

Board: 2 copper layers, 127.0 x 82.5 mm, 48 parts (1 on the bottom side), 89 nets.

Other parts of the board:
U$1: LOGO_FABIO_SILK_300MIL

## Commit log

2024-02-11 Primeiro envio
    [MA163.sch]
2024-02-15 Preparado board para roteamento
    [MA163.brd, MA163.sch]
2024-02-15 Mais roteamento
    [MA163.brd, MA163.sch]
2024-02-18 Roteamento finalizado
    [MA163.brd]
2024-02-20 Documentação
    [MA163.brd, MA163.sch, link.cfg]
2024-02-21 Adicionado link para Github Pages
2024-03-04 Adicionado silks da Microdigital e FBLabs
    [MA163.brd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]
